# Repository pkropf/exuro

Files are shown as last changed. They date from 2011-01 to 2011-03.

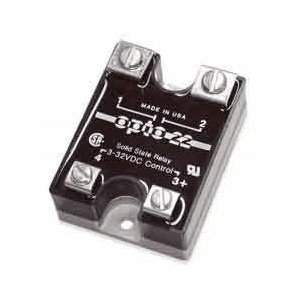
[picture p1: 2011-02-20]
pycon 2011/poster session.graffle/image8.jpg

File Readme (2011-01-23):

Exuro
-----

Exuro is a small robot that uses an arduino to control 4 servo motors that move a pair of gimbal based eyes, it uses a Kinect to find interesting things to focus the eyes on and controls a small propane based fire poofer through a solid state relay connected to the arduino.

Other Notes
===========

Using Hextronik HX5010 servos. Orange is control, red is power and brown is ground.

The code running on the Arduino board and the Python code interfacing with it were originally based on the work of Brian D. Wendt at http://principialabs.com/. The code came from his project at: http://principialabs.com/arduino-python-4-axis-servo-control/.

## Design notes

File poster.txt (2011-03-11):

Here's the description for a poster session for PyCon 2011 in Atlanta, GA.

Title: Interactions with Python and Kinect

Description: Python, Kinect and Arduino are excellent tools to interact with the physical world. Using them, a small, interactive robot is being created to showcase skills and techniques that can be learned at The Crucible, a non-profit industrial arts education center located in Oakland, CA.

Type: Poster

Abstract: In 2010, Microsoft introduced the Kinect for use with their Xbox 360. It provides a set of sensors that allow people to interact with a game without using a controller. Soon after it's release, Adafruit Industries created a bounty for open source drivers to allow anyone to use the Kinect for other purposes. Within a week, the first open source drivers were released.

The robot is being created using Python, a computer, a Kinect, stainless steel, an Arduino microcontroller, servo motors, a bill acceptor, a solenoid valve, a spark plug and a neon transformer. Using the Kinect to locate the closest person, the eyes of the robot track the person as they remain in its field of vision. Using pre-recorded sentences, the robot attempts to interact with the person and encourages them to make a donation.

This session will discuss the use of Python to extract working data from a Kinect, communicating with an Arduino controller and techniques for real world interactions.

Audience level: Experienced

Submitting speaker: Peter Kropf

details
=======

hardware
--------

computer, arduino, kinect, servos, solid state relay, switches, bill acceptor, solenoid, propane, neon transformer, spark plug, recycled stainless steel.

computer - connected to kinect and arduino; running ubuntu 10.10 64bit, python; polls arduino for depth and rgb feeds, parses depth for closest point, calculates angles for servos, sends message to arduino to move servos; pulls bill acceptor and trip switch data; saves depth, video, donation amount, kinect time, system time.

kinect - 640 x 480 rgb camera, infrared projector, 640 x 480 infrared camera, 4 microphones array, 30 fps, 57° horizontally / 43° vertically field of view

arduino board - sketches, controlling servos and solid state relays, sensing inputs from trigger switch and bill acceptor, communicating via usb / serial w/ computer.

servos - 2 servos / eye.

stainless - recycled materials from bayer pharmaceuticals in emeryville, ca.

poofer - stainless tank, 120 volt solenoid, propane fuel source w/ regulator, spark plug for ignition, solid state relay controlled by arduino to activate solenoid and igintion.

software
--------

arduino sketch

python code

    * opencv
    * pyserial
    * numpy
    * openkinect

open source tools
+++++++++++++++++

github, python, libfreenect, opencv

on linux, use virtualenv. get latest cython and build w/ virtualenv.

props
-----

kinect, arduino, single eye on small base, 2 servos, solid state relay (only if it's contained in a safe electrical box)

printed
-------

4' x 8' board of details

post cards, zazzle or vista print

  * project name
  * website or github url
  * picture of eyes
  * picture of poof
  * my contact info
  * exuro's facebook page, twitter account

8 - 10 11" x 17" pages can be easily displayed on a 4' x 4' board

2 pages to show hardware and data flow, 1 for the computer and 1 for the arduino
page to show eye angle problem
page to list out hardware w/ pictures
page (horizontal) for project title, include image of eyes
page showing poofer going off

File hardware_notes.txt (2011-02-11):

Hardware Notes
--------------

Arduino

feed from arduino to robot head has N connections:

1) ground
2) power
3) left eye horizontal servo control
4) left eye vertical servo control
5) left eye led
6) right eye horizontal servo control
7) right eye vertical servo control
8) right eye led
9) belly led

Control Cable
=============

14 pin plug amp receptacle 206043-1R / jameco 495146, plug 206044-1R / jameco 495031

pin 1   pink            left eye power
pin 2   light green     left eye ground
pin 3   white           left eye horizontal control     arduino 9
pin 4   brown           left eye vertical control       arduino 10 
pin 5   blue            left eye led
pin 6   red / black     right eye power
pin 7   red             right eye ground
pin 8   dark blue       right eye horizontal control    arduino 12
pin 9   orange          right eye vertical control      arduino 11
pin 10  brown / black   right eye led
pin 11  purple          body led power
pin 12  yellow          body led ground
pin 13  orange / black  not used
pin 14  green           not used

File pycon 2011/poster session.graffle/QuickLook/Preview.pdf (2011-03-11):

# Interactions with Python, Arduino and Kinect

# Peter Kropf pkropf@gmail.com

# github.com/pkropf/exuro

# Poofer!

# Hardware

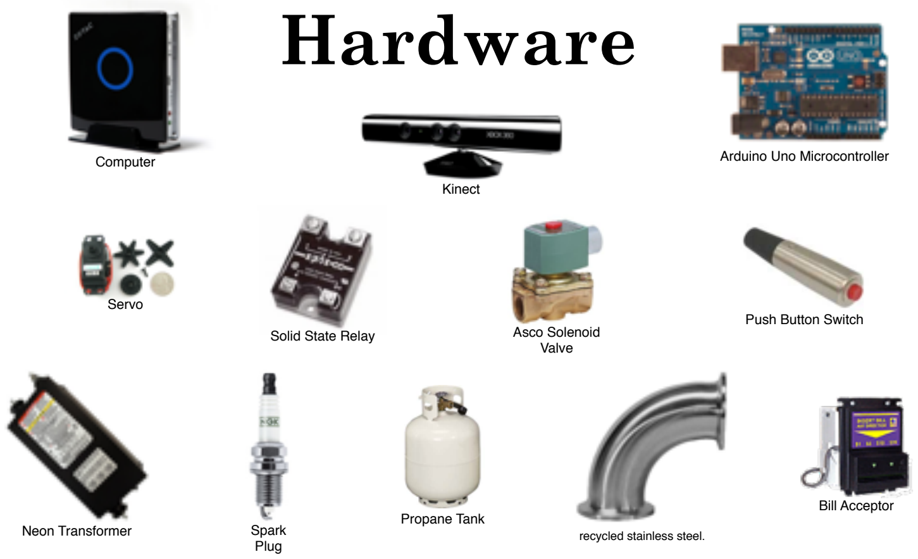
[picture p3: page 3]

Computer | Arduino Uno Microcontroller

Kinect

Servo

Asco Solenoid
Valve Solid State Relay

Push Button Switch

Neon Transformer | Propane Tank
Spark
Plug

Bill Acceptor

recycled stainless steel.

# Kinect

# Arduino

640 x 480 rgb camera for video

infrared projector

640 x 480 infrared camera for depth

4 microphones array

30 fps

57° horizontal / 43° vertical field of view

ATmega328

5V

7-12V

14 (6 w/ PWM)

6

40 mA
32 KB
2 KB

1 KB

16 MHz

Microcontroller

Operating Voltage

Input Voltage

Digital I/O Pins

Analog Input Pins

DC Current / I/O Pin

Flash Memory

SRAM

EEPROM

Clock Speed

# Software

## Computer / Arduino / Kinect Interaction

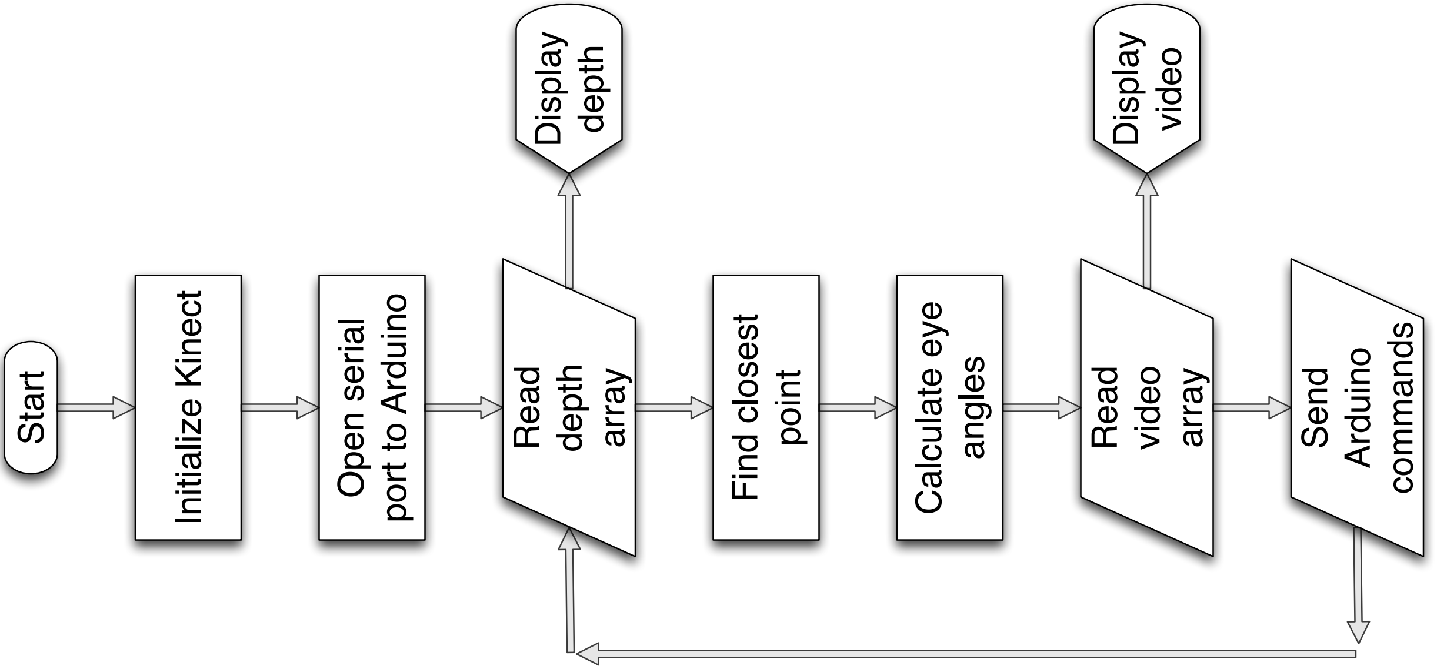
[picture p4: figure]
Start; Read; depth; array; Display; Initialize Kinect; Open serial; port to Arduino; Find closest; point; Send; Arduino; commands; Calculate eye; angles; video

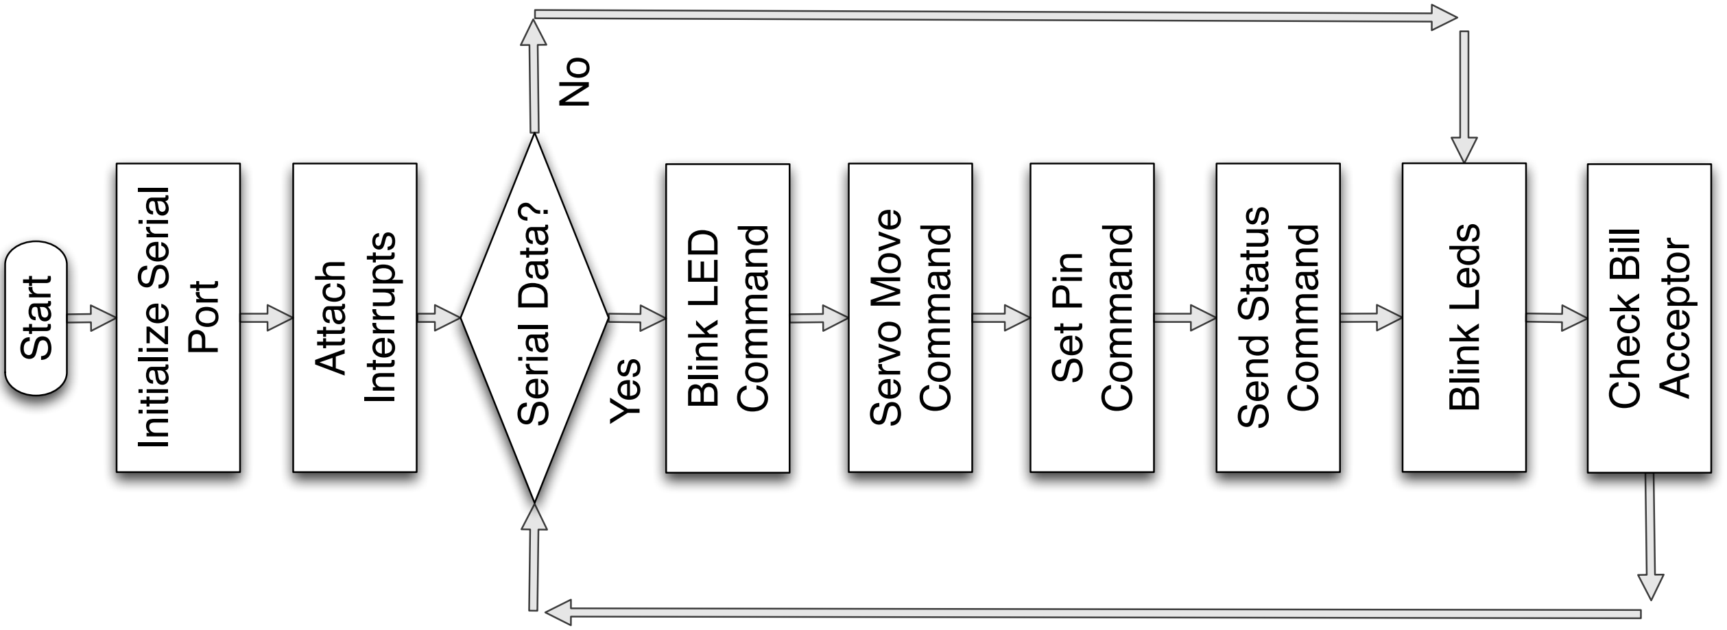
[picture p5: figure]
Start; Initialize Serial; Port; Attach; Interrupts; Blink LED; Command; Serial Data?; Yes; Blink Leds; Check Bill; Acceptor; Servo Move; Set Pin; Send Status

## Arduino Flow

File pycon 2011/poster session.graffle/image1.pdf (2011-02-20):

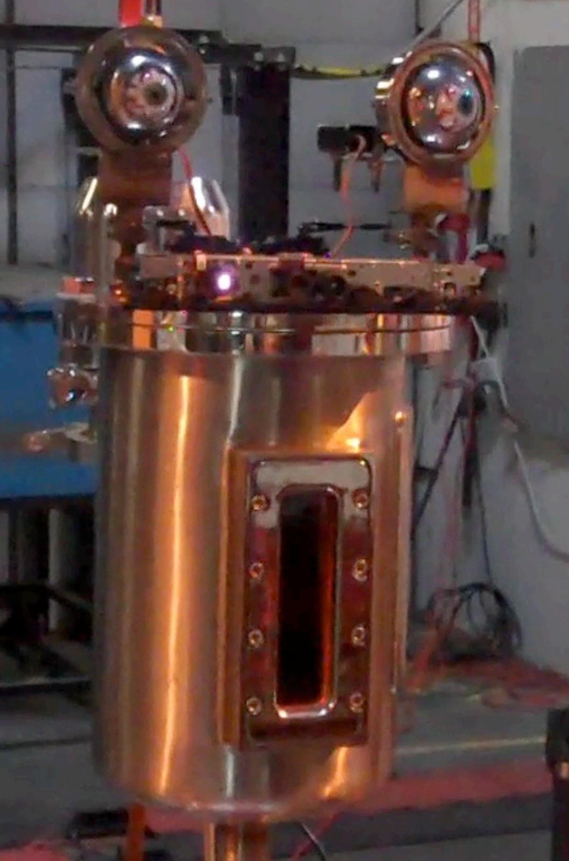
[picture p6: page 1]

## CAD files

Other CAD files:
kinect distance.skp
kinect screens.skp
poster.skp

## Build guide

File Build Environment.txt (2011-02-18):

Notes on creating the needed build environment

apt-get install python-virtualenv python-dev cmake g++ libusb-1.0-0 libusb-1.0-0-dev glutg3-dev libxmu-dev libxi-dev python-numpy python-opencv

easy_install python-twitter
easy_install oauth2
easy_install Tweepy
easy_install gdata

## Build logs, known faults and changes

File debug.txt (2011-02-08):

0.554942061345 (84, 83) 53.3779139371 153.948533799 283.451935961 -36.6220860629 63.9485337985 -1
move right eye to 53.3779139371 153.948533799
0.555863549042 (87, 80) 53.4559478074 26.1158570039 282.646422231 -36.5440521926 63.8841429961 -1
move left eye to 53.4559478074 26.1158570039
0.555863549042 (87, 80) 53.4559478074 153.884142996 282.646422231 -36.5440521926 63.8841429961 -1
move right eye to 53.4559478074 153.884142996
0.556787957235 (58, 63) 50.338002481 23.6648213087 316.185072386 -39.661997519 66.3351786913 -1
move left eye to 50.338002481 23.6648213087
0.556787957235 (58, 63) 50.338002481 156.335178691 316.185072386 -39.661997519 66.3351786913 -1
move right eye to 50.338002481 156.335178691
0.558645591739 (58, 61) 50.2380769223 23.5901696522 317.308997666 -39.7619230777 66.4098303478 -1
move left eye to 50.2380769223 23.5901696522
0.558645591739 (58, 61) 50.2380769223 156.409830348 317.308997666 -39.7619230777 66.4098303478 -1
move right eye to 50.2380769223 156.409830348
0.559578846598 (59, 72) 50.8573988168 24.0565657821 310.394909752 -39.1426011832 65.9434342179 -1
move left eye to 50.8573988168 24.0565657821
0.559578846598 (59, 72) 50.8573988168 155.943434218 310.394909752 -39.1426011832 65.9434342179 -1
move right eye to 50.8573988168 155.943434218
0.561454303592 (63, 62) 50.6566359972 23.9043993969 312.622775882 -39.3433640028 66.0956006031 -1
move left eye to 50.6566359972 23.9043993969
0.561454303592 (63, 62) 50.6566359972 156.095600603 312.622775882 -39.3433640028 66.0956006031 -1
move right eye to 50.6566359972 156.095600603
0.561454303592 (56, 72) 50.6297846066 23.8841191807 312.92171545 -39.3702153934 66.1158808193 -1
move left eye to 50.6297846066 23.8841191807
0.561454303592 (56, 72) 50.6297846066 156.115880819 312.92171545 -39.3702153934 66.1158808193 -1
move right eye to 50.6297846066 156.115880819

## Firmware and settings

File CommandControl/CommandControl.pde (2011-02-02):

// based on the code from http://principialabs.com/arduino-python-4-axis-servo-control/

// Copyright (c) 2011 Peter Kropf. All rights reserved.
//
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
#include <Servo.h> 

#define SERVO_COUNT   4
#define LED_COUNT     1
#define PIN_COUNT     4

#define CMD_BLINK           0  // blink an led
#define CMD_SERVO           1  // move a servo
#define CMD_REGISTER_SWITCH 2  // register a switch on a pin
#define CMD_READ_SWITCH     3  // read the status of a switch, open / closed
#define CMD_PIN             4  // set a pin to the specified voltage


Servo servo[SERVO_COUNT];
int servo_pin[SERVO_COUNT];

int led[LED_COUNT];          // state of the led's
int led_counter[LED_COUNT];  // number of times remaining to toggle the led's
int led_pin[LED_COUNT];      // map of index id to led pin
long led_millis = 0;         // time the last blink happened

int minPulse = 600;   // minimum servo position, us (microseconds)
int maxPulse = 2400;  // maximum servo position, us

int startbyte;       // start byte, begin reading input
int cmd;             // what command are we doing?
int parm1;           // command parameter 1
int parm2;           // command parameter 2
int i;               // iterator

int relay_pin = 4;
int relay_state = LOW;


void setup()
{
  Serial.begin(9600);                    // setup the serial port for communications with the host computer

  for (i=0; i < SERVO_COUNT; i++) {      // initialize the servo_pin map to a known set of values
    servo_pin[i] = -1;
  }

  for (i=0; i < LED_COUNT; i++) {        // initialize the led_pin map to a known set of values
    led_pin[i] = -1;
    led_counter[i] = 0;
  }

  pinMode(relay_pin, OUTPUT);
  attachInterrupt(0, toggle_relay2, CHANGE);
  // attachInterrupt(0, toggle_relay, CHANGE);
  // attachInterrupt(0, relay_on, RISING);
  // attachInterrupt(0, relay_off, FALLING);
} 


void set_led(int pin, int blinks)
{
  int i;

  for (i=0; i < LED_COUNT; i++) {      // look for a matching servo
    if (led_pin[i] == pin) {
      led_counter[i] = blinks;
      break;
    }
  }

  if (i == LED_COUNT) {                // no servo found so add one to the first available slot
    for (i=0; i < LED_COUNT; i++) {
      if (led_pin[i] == -1) {
        led_pin[i] = pin;
        led_counter[i] = blinks;
        pinMode(pin, OUTPUT);
        break;
      }
    }
  }
}


void blink_leds()
{
  int i;
  unsigned long now = millis();

  if(now - led_millis > 1000) {
    led_millis = now;

    for (i=0; i < LED_COUNT; i++) {
      if (led_counter[i] > 0) {
        if (led[i] == LOW) {
          led[i] = HIGH;
        } else {
          led[i] = LOW;
          led_counter[i] = led_counter[i] - 1;
        }

        digitalWrite(led_pin[i], led[i]);
      }
    }
  }
}


void move_servo(int pin, int angle)
{
  int i;

  for (i=0; i < SERVO_COUNT; i++) {      // look for a matching servo
    if (servo_pin[i] == pin) {
      servo[i].write(angle);
      break;
    }
  }

  if (i == SERVO_COUNT) {                // no servo found so add one to the first available slot
    for (i=0; i < SERVO_COUNT; i++) {
      if (servo_pin[i] == -1) {
        servo_pin[i] = pin;
        servo[i].attach(pin, minPulse, maxPulse);
        servo[i].write(angle);
        break;
      }
    }
  }
}


void toggle_relay()
{
  relay_state = !relay_state;
}


void toggle_relay2()
{
  int val = digitalRead(2);

  if (val == LOW) {
    relay_state = LOW;
  } else {
    relay_state = HIGH;
  }
}

void relay_on()
{
  relay_state = HIGH;
}


void relay_off()
{
  relay_state = LOW;
}


void loop() 
{
  if (Serial.available() > 3) { // Wait for serial input (min 4 bytes in buffer)
    startbyte = Serial.read();
    if (startbyte == 255) {     // header byte to every command packet set
      cmd = Serial.read();      // what are we going to do?
      if (cmd == 255) {         // make sure it isn't a header byte
        return;
      }

      parm1 = Serial.read();    // get the first parameter
      if (parm1 == 255) {       // make sure it isn't a header byte
        return;
      }

      parm2 = Serial.read();    // get the second parameter
      if (parm2 == 255) {       // make sure it isn't a header byte
        return;
      }

      switch (cmd) {
          case CMD_BLINK:
            set_led(parm1, parm2);
            break;
          case CMD_SERVO:
            move_servo(parm1, parm2);
            break;
          case CMD_PIN:
            pinMode(parm1, OUTPUT);
            if (parm2 == 0) {
                digitalWrite(parm1, LOW);
            } else {
                digitalWrite(parm1, HIGH);
            }
            break;
          case CMD_REGISTER_SWITCH:
          case CMD_READ_SWITCH:
            break;
      }
    }
  }
  blink_leds();
  digitalWrite(relay_pin, relay_state);
}

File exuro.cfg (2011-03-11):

[arduino]
#
# port - the file path to access the serial port for communications
# with the arduino
#
# reset_time - how long in seconds to wait for the arduino to reset
# when there's a communications failure.
#
# baud - communication speed used when talking with the arduino
#

port        = /dev/ttyACM0
reset_time  = 2.0
#baud        = 9600
baud        = 57600


[kinect]
#
# height - the distance in meters from the kinect sensor to the floor.
#
# x - resolution width of the image and depth arrays
#
# y - resolution height of the image and depth arrays
#
# hfield - horizontal field of view
#
# vfield - vertical field of view
#

height  = 1.686
x       = 640
y       = 480
hfield  = 57
vfield  = 43


[left eye]
#
# active - flag indicating if the left eye is currently online
#
# horizontal - the arduino port used to control the left eye
# horizontal servo.
#
# vertical - the arduino port used to control the left eye
# vertical servo.
#
# offset - the distance in meters from the center axis to the center
# of the eye.
#
# height - the distance in meters from the center of the eye to the
# floor.
#
# hmin - minimum allowed value for the left eye horizontal movement
#
# hmax - maximum allowed value for the left eye horizontal movement
#
# horient - looking out from the eye's point of view, horient
# describes what happens to the hoizontal servo when moving to the
# hmin position. 1 indicates that it moves to the right, -1 indicates
# that it moves to the left.
#
# vmin - minimum allowed value for the left eye vertical movement
#
# vmax - maximum allowed value for the left eye vertical movement
#
# vorient - looking out from the eye's point of view, vorient
# describes what happens to the vertical servo when moving to the vmin
# position. 1 indicates that it moves up, -1 indicates that it moves
# down.
#

active      = True
horizontal  = 10
vertical    = 9
hmin        = 20
hmax        = 160
horient     = -1
vmin        = 85
vmax        = 160
vorient     = 1
offset      = -0.10636
height      = 1.753


[right eye]
#
# active - flag indicating if the right eye is currently online
#
# horizontal - the arduino port used to control the right eye
# horizontal servo.
#
# vertical - the arduino port used to control the right eye vertical
# servo.
#
# offset - the distance in meters from the center axis to the center
# of either eye.
#
# height - the distance in meters from the center of an eye to the
# floor.
#
# hmin - minimum allowed value for the left eye horizontal movement
#
# hmax - maximum allowed value for the left eye horizontal movement
#
# horient - looking out from the eye's point of view, horient
# describes what happens to the hoizontal servo when moving to the
# hmin position. 1 indicates that it moves to the right, -1 indicates
# that it moves to the left.
#
# vmin - minimum allowed value for the left eye vertical movement
#
# vmax - maximum allowed value for the left eye vertical movement
#
# vorient - looking out from the eye's point of view, vorient
# describes what happens to the vertical servo when moving to the vmin
# position. 1 indicates that it moves up, -1 indicates that it moves
# down.

#active     = True
active     = False
horizontal = 12
vertical   = 11
hmin       = 40
hmax       = 170
horient    = -1
vmin       = 30
vmax       = 160
vorient    = -1
offset     = 0.10636
height     = 1.753


[servo]
#
# pause - time in seconds before sending the next servo command
#
# limit_watch - if true, when the the servo is to be moved more than
# the min or max reset the value to the min or max. when false, raise
# ValueError.
#

pause = 0.1
#limit_watch = True
limit_watch = False


[general]
#
# debug - boolean to turn on / off debugging
#

debug = True
#debug = False


[keys]
#
# consumer_key - twitter consumer key
#
# consumer_secret - twitter consumer secret
#
# access_key - twitter access key
#
# access_secret - twitter access secret
#

consumer_key    = MISSING
consumer_secret = MISSING
access_key      = MISSING
access_secret   = MISSING

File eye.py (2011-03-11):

#! /usr/bin/env python

# Copyright (c) 2011 Peter Kropf. All rights reserved.
#
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

from commands import Servo
import cfg
from time import sleep
import math


class Eye(object):
    def __init__(self, name, active,
                 horizontal_pin, vertical_pin, 
                 hmin, hmax, vmin, vmax,
                 port, offset, 
                 height,
                 horient, vorient):
        self.name = name
        self.active = active
        self.hpin = horizontal_pin
        self.vpin = vertical_pin
        self.hmin = hmin
        self.hmax = hmax
        self.vmin = vmin
        self.vmax = vmax
        self.port = port

        if self.active:
            self.hservo = Servo(self.hpin, self.hmin, self.hmax, port)
            self.vservo = Servo(self.vpin, self.vmin, self.vmax, port)
        else:
            self.hservo = None
            self.vservo = None

        self.offset = offset
        self.height = height
        self.horient = horient
        self.vorient = vorient
        self.move(*self.center())
        self.focus = self.focus_simple
        #self.focus = self.focus_angles

        if cfg.general.debug:
            print self.name, self.hpin, self.vpin, self.port, self.offset
            print self.hservo
            print self.vservo


    def __unicode__(self):
        return self.name


    def settings(self):
        print 'name:',    self.name
        print 'active:',  self.active
        print 'hpin:',    self.hpin
        print 'vpin:',    self.vpin
        print 'hmin:',    self.hmin
        print 'hmax:',    self.hmax
        print 'vmin:',    self.vmin
        print 'vmax:',    self.vmax
        print 'port:',    self.port
        print 'hservo:',  self.hservo
        print 'vservo:',  self.vservo
        print 'offset:',  self.offset
        print 'height:',  self.height
        print 'horient:', self.horient
        print 'vorient:', self.vorient


    def center(self):
        return self.hmin + ((self.hmax - self.hmin) / 2.0), self.vmin + ((self.vmax - self.vmin) / 2.0)


    def move(self, horizontal, vertical):
        if self.active:
            self.hservo.send(horizontal)
            self.vservo.send(vertical)


    def focus_simple(self, distance, point):
        """distance in meters.
        point is x, y tuple for location in grid space.

        angle of focus is currently very simplistic. it doesn't yet
        take into account that the eyes are offset from the center and
        it doesn't yet take into account the distance of the point in
        question.

        calculating the angle of focus depends on how the servo is
        oriented and moves. if a low value moves the servo to the left
        or up, then the calculation is:

            range of movement * percentage of x as related to the
            scale of the axis

        if a high value moves the servo to the left or up, then the
        calculation is:

            axis max - range of movement * percentage of x as related
            to scale of the axis
        """

        xpercent = (self.hmax - self.hmin) * (point[0] / float(cfg.kinect.x))
        ypercent = (self.vmax - self.vmin) * (point[1] / float(cfg.kinect.y))

        if self.horient == 1:                # movement scale goes from high to low
            x = self.hmin + xpercent
        else:                                # movement scale goes from low to high
            x = self.hmax - xpercent


        if self.vorient == 1:                # movement scale goes from high to low
            y = self.vmin + ypercent
        else:                                # movement scale goes from low to high
            y = self.vmax - ypercent

        if cfg.general.debug:
            print self.name, distance, point, x, y

        self.move(x, y)


    def focus_angles(self, distance, point):
        """distance in meters.
        point is x, y tuple for location in grid space.

        to calculate the focus for an eye on the x axis:

            1) calculate the distance of the known point (px, py) to the center (cx, cy):

                 radius = sqrt(((px - cx) ** 2) + ((py - cy) ** 2))

                 where:

                     cx, cy = 640 / 2, 480 / 2

            2) calculate the distance in pixels from the kinect to the center of the 
               640x480 field:

                 x_to_center = 320 / tan(kinect_field_x / 2)

                 where:
                     320 is 1/2 of the horizontal field (sets up for a right triangle)
                     kinect_field_x is the kinect's field of vision along the x axis.

            3) x_angle = atan(radius / x_to_center)

        for the y axis:

            1) same as for x axis

            2) y_to_center = 240 / tan(kinect_field_y / 2)

                where 240 is 1/2 of the vertical field and kinect_field_y is the kinect's
                field of vision along the y axis.

            3) y_angle = atan(radius / y_to_center)
        """

        radius = math.sqrt(((point[0] - 320) ** 2) + ((point[1] - 240) ** 2))

        x_to_center = 320 / math.tan(math.radians(cfg.kinect.x / 2))
        x_angle = math.degrees(math.atan(radius / x_to_center))

        y_to_center = 240 / math.tan(math.radians(cfg.kinect.y / 2))
        y_angle = math.degrees(math.atan(radius / y_to_center))

        if self.horient == 1:                # movement scale goes from high to low
            x = 90 - x_angle
        else:                                # movement scale goes from low to high
            x = 90 + x_angle


        if self.vorient == 1:                # movement scale goes from high to low
            y = 90 - y_angle
        else:                                # movement scale goes from low to high
            y = 90 + y_angle

        if cfg.general.debug:
            print distance, point, x, y, radius, x_angle, y_angle, self.horient

        self.move(x, y)


Left  = Eye('left eye', cfg.eye.left.active,
            cfg.eye.left.hpin, cfg.eye.left.vpin,
            cfg.eye.left.hmin, cfg.eye.left.hmax, 
            cfg.eye.left.vmin, cfg.eye.left.vmax,
            cfg.arduino.port, 
            cfg.eye.left.offset, cfg.eye.left.height,
            cfg.eye.left.horient, cfg.eye.left.vorient)

Right = Eye('right eye', cfg.eye.right.active,
            cfg.eye.right.hpin, cfg.eye.right.vpin, 
            cfg.eye.right.hmin, cfg.eye.right.hmax, 
            cfg.eye.right.vmin, cfg.eye.right.vmax,
            cfg.arduino.port,
            cfg.eye.right.offset, cfg.eye.right.height,
            cfg.eye.right.horient, cfg.eye.right.vorient)
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

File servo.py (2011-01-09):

#!/usr/bin/env python

# hacked by Peter Kropf (pkropf@gmail.com)

# based on the code from http://principialabs.com/arduino-python-4-axis-servo-control/

# originally:
# Created:  23 December 2009
# Author:   Brian D. Wendt (http://principialabs.com/)
# Version:  1.0
# License:  GPLv3 (http://www.fsf.org/licensing/)


import serial


class Servo(object):
    def __init__(self, pin, port):
        self.pin = pin
        self.port = port
        self.serial = None
        self.setup()

    def setup(self):
        self.serial = serial.Serial(self.port, 9600, timeout=1)
        #print self.serial

    def move(self, angle):
        try:
            if (0 <= angle <= 180):
                self.serial.write(chr(255))         # header, start of a new command set
                self.serial.write(chr(1))           # command to move the servo
                self.serial.write(chr(self.pin))    # connected to pin
                self.serial.write(chr(angle))       # to this angle

            else:
                raise ValueError, "Servo angle must be an integer between 0 and 180."

        except serial.serialutil.SerialException:
            self.setup()

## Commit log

2011-01-08 basic working communication from Python to the Arduino controlling the servos.
2011-01-09 first pass at extending the ServoControl module into a multifunction module that allows for moving servos, blinking led's, reading switches and setting specific pins high or low.
2011-01-09 moved the servo and blink commands into the commands.py file. added a base class for the common work in communicating with the arduino.
2011-01-09 moved the logic of communicating with the arduino board over a serial connection to the Command class. this simplifies the implementation of the Blink and Servo classes though it does change the name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
2011-01-09 now using the Servo object from commands.py.
2011-01-10 added command to set an individual pin high or low. currently assumes that a digital pin is being accessed.
2011-01-14 added code to move the two servos for an eye as one unit. moved the test for time since last servo move to the Servo class.
2011-01-15 fixed the pin command.
    [CommandControl.pde, commands.py]
2011-01-15 discovered that the arduino can falsely detect (or possibly miss) an interrupt and thus cause the relay to be always on. instead of looking for a change and just toggling the state, read the current 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
2011-01-22 added demo_cv_sync from the libfreenect wrappers/python directory. they will serve as a starting point to figure out how to find real-world distance and track people.
2011-01-23 added a script to extract the data from a depth frame. added depth to meters calculation.
2011-01-23 added a demo program to allow for viewing the depth data through filters.
2011-01-29 added a configuration file instead of having values hardcoded in all the programs. added a LeftEye and RightEye to the eye.py module. added a couple of more work-in-progress demos for interacting wit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
    [exuro.cfg]
2011-01-29 removed eyes.py since the logic is now basically within the __name__ == main section of eye.py. moved the servo pause time to the configuration file. moved the time_reset to be reset_time in the conf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
    [exuro.cfg]
2011-01-30 work towards finding objects in the kinect rgb and depth cameras
2011-02-02 added show_closest2 and demo_cv_threshold2 to test a theory of some simpler logic to find the closest item. instead of trying to find objects in the image and then determine their relative distance t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
2011-02-04 added a small buffer to track the last set of closest locations to cut down on the jittery tracking dot. not sure if this will be a problem when the arduino is moving the servos.
2011-02-04 added track.py to test the relation between x, y, depth values and moving the eyes.
2011-02-04 added explaination comments to the exuro.cfg file. added distance measurements for the kinect height, eye height and eye offset.
    [exuro.cfg]
2011-02-04 added the kinect image resolution to the config file. added dummy function to cause an eye to focus on a point some distance away. added randomizer to pseudo-test the eye focus. added call to the eye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
    [exuro.cfg]
2011-02-04 first pass at calculating the eye angles. (needs more work.)
    [exuro.cfg]
2011-02-05 added software range limiting to the servo motors.
    [exuro.cfg]
2011-02-05 created a cfg module to hold configuration data and segregate it into namespaces.
    [exuro.cfg]
2011-02-05 added orientation configuration details to the left and right eye servos. this is needed to allow for the correct calculations when moving an eye.
    [exuro.cfg]
2011-02-05 added the orient of the servos to the eyes. next implementation of the algorithm to focus the eyes on a point in space.
2011-02-06 added notes file to track ideas on how to interact with a kinect.
2011-02-06 mostly working eye tracking. unfortunately the when the closest point is down, the eyes move up and vise-versa.
    [exuro.cfg]
2011-02-07 fixed the orientation on a couple of servos. added a short movement buffer in an attempt to reduce the jittery movement of the eyes.
    [exuro.cfg]
2011-02-10 changed the pins on the arduino for the eye servos to match using the new wiring harness.
    [exuro.cfg]
2011-02-11 added hardware note on right eye arduino pins.
2011-02-18 setup exuro_local.cfg to override values read from exuro.cfg. added an flag to make the eyes active or inactive. this will allow use of the eye module without having an arduino connected to the syste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
    [exuro.cfg]
2011-02-19 collecting ideas on how to present at the PyCon 2011 poster session.
    [kinect distance.skp, kinect screens.skp, poster.skp]
2011-02-20 started work on the material for the poster session at pycon.
2011-03-07 added image of exuro poofing.
    [kinect distance.skp]
2011-03-08 added arduino flow overview.
2011-03-11 reduced the movement buffer for servos from 3 to 1. added a settings method to Eye to display the configuration details. updated the calculations for focus_simple to fix problems with calculating the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
    [exuro.cfg]
